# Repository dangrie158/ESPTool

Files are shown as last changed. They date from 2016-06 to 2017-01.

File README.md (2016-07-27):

# ESPTool
## A WiFi Security Swiss Army Knife

The ESPTool is a convenient Tool to test your WiFi Security against attackers.
It can demonstrate how easy it is to crack a WiFi Password or jam your WiFi so you cant access the internet.
This Tool is designed for education and self tests.

**Be aware that it is illegal to use this device on Networks other than your own.**

_**Disclaimer** The authors of this reposity are not accountable for any action users may perform with this tool_

## Hardware

The Hardware is designed to be a relative generic and reusable Module around the ESP8266 WiFi Plattform. The Schematic is loosley based on the [NodeMCU](http://nodemcu.com) Project, however instead of breaking out all the free pins, all pins are used for a bunch of devices.

The Device has the following Hardware

* SSD1306 based OLED Display, connected via I2C
* microSD Card Socket connected over the SPI interface
* 3 general purpose buttons
* ESP8266-12E Module
* TPS63031 Buck-/Boost-Converter with an input range from 1.8V - 5.5V
* MCP73831 Single-Cell LiPo Charger Chip
* CP2012 USB to UART converter Chip

## Software
The software is of course the part where all the security features are implemented.

It still is under heavy development. A List of planned features are listed here:

* Layer 1:
	* *Since the ESPs Radio is not really configurable it is not possible to create a WiFi Jammer that works by emitting broadband noise or any other Layer 1 attacks*
* Layer 2:
	* [Deauthentification attack](https://en.wikipedia.org/wiki/Wi-Fi_deauthentication_attack)
	* collecting authentification frames and save the keys to SD card for later decryption (using a wordlist on a computer, the ESP neither has enough memory nor enough processing power to crack them on the system)
	* arp spoofing and session hijacking when connected (needs investigation)
* Layer 3 (after connecting to an AP):
	* Host discovery (IP Scanner)
	* Ping flooding (ICMP Pings)
* Layer 4 (after connecting to an AP):
	* Port Scan on Host

### Incognito Features (TBD):
* Random MAC-Address on Power Up
* Random Mac Address while performing critical Tasks

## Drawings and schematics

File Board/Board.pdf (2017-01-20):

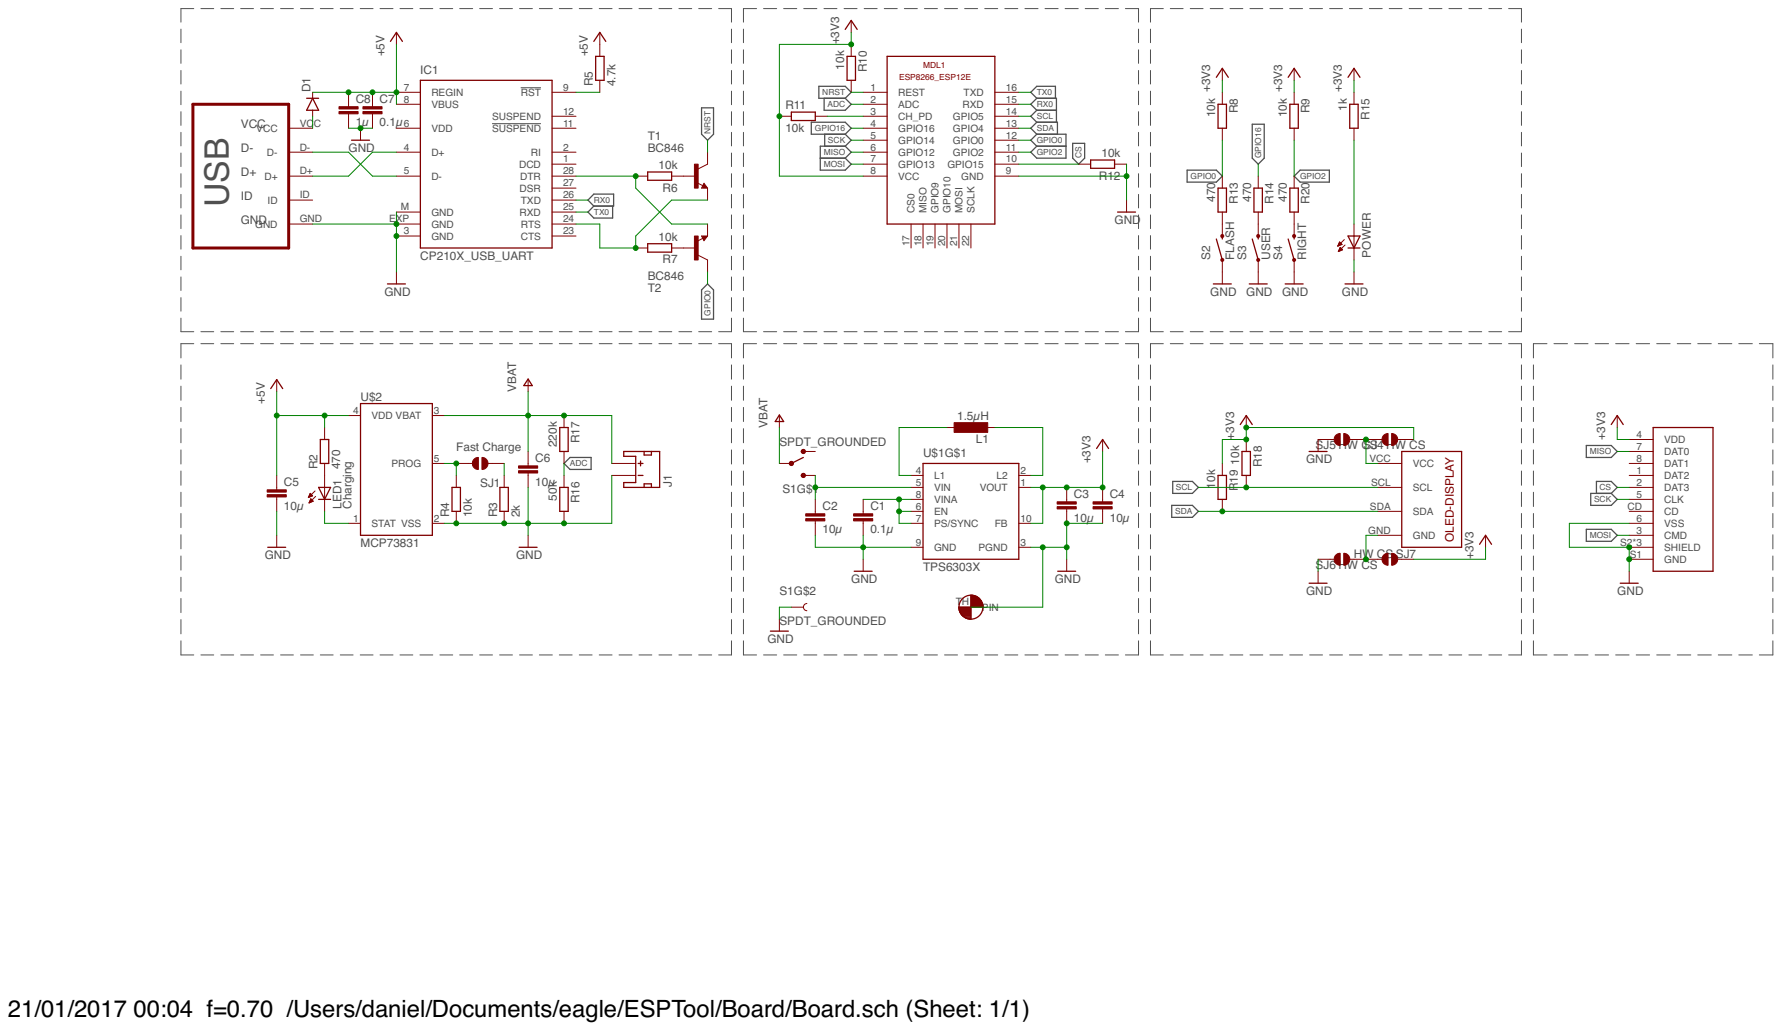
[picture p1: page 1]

HW CS HW CS GND

21/01/2017 00:04 f=0.70 /Users/daniel/Documents/eagle/ESPTool/Board/Board.sch (Sheet: 1/1)

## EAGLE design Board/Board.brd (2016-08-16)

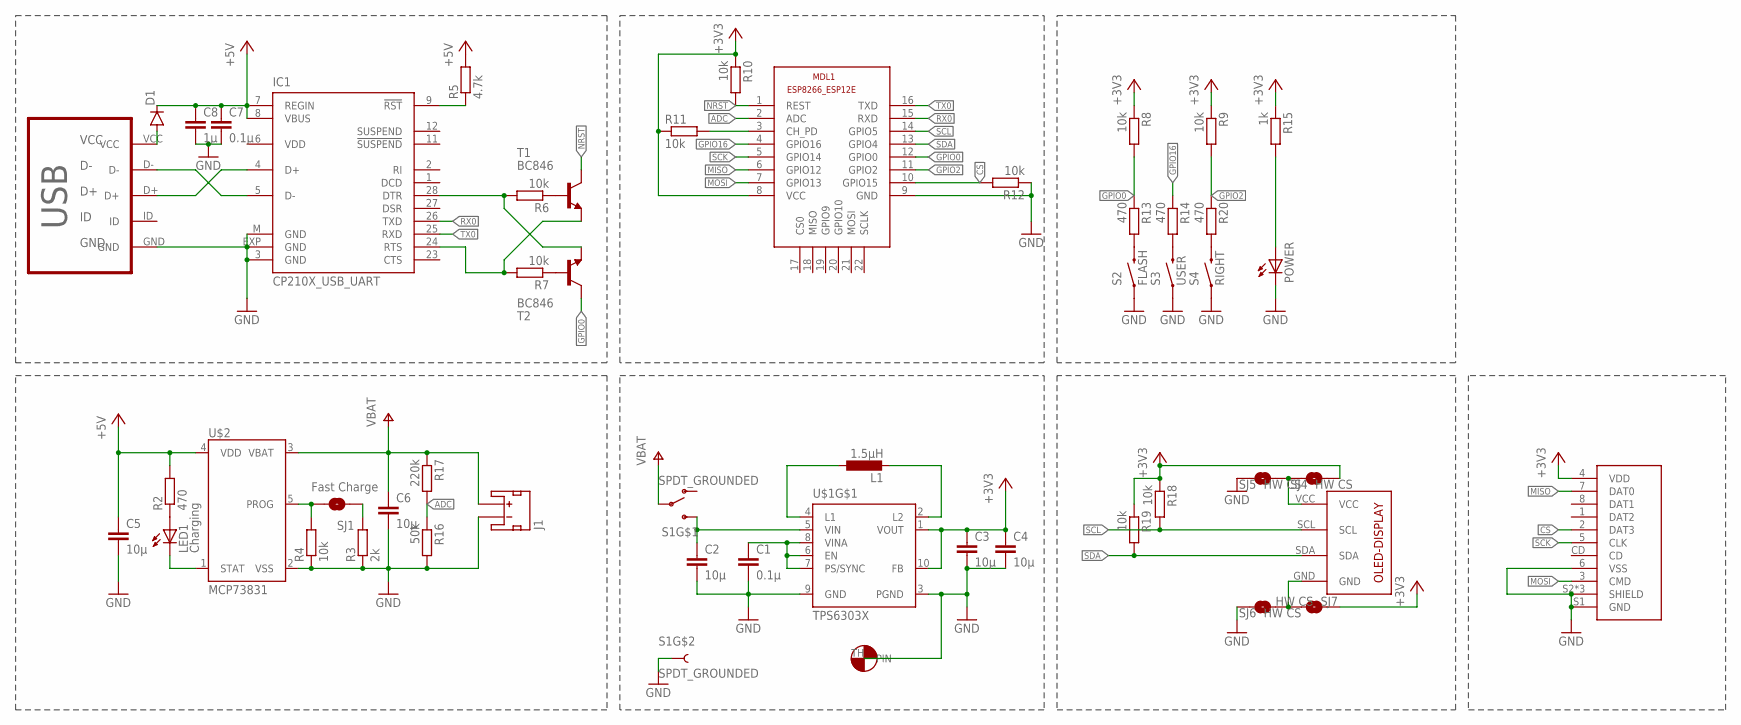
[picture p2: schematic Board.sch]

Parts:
C1, C7: 0.1µ; C0603
C2, C3, C4, C5, C6: 10µ; C0603
C8: 1µ; C0603
D1: DIODEBAS16; SOD-323
IC1: CP210X_USB_UART; MLP28
J1: JST_2MM_MALE; JST-2-SMD
L1: 1.5µH; L3225P
LED1: Charging; SML0805
MDL1: ESP8266-12EESP8266-ESP12E; ESP8266-ESP12E
POWER: LEDSML0805; SML0805
R2, R13, R14, R20: 470; R0603
R3: 2k; R0603
R4, R6, R7, R8, R9, R10, R11, R12, R18, R19: 10k; R0603
R5: 4.7k; R0603
R15: 1k; R0603
R16: 50k; R0603
R17: 220k; R0603
S1: SPDT_GROUNDED; SWITCH-SPST-SMD-A
S2: FLASH; TACTILE-SWITCH-1101NE
S3: USER; TACTILE-SWITCH-1101NE
S4: RIGHT; TACTILE-SWITCH-1101NE
SJ1: Fast Charge; SJ_2S-NO
SJ4, SJ5, SJ6, SJ7: HW CS; SJ_2S-NO
T1, T2: BC846; SOT23
U$1: TPS6303X; DSK10
U$2: MCP73831; SOT23-5
U$3: MICRO-USB-B; MICRO_USB_4_LEGS
U$4: MICRO_SD_SOCKET; MICRO_SD
U$6: OLED-I2C

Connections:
+3V3: C3.1, C4.1, MDL1.8 (VCC), R8.1, R9.1, R10.1, R11.1, R15.1, R18.1, R19.1, SJ4.1, SJ7.2, U$1.1 (VOUT), U$1.10 (FB), U$4.4 (VDD)
+5V: C5.1, C7.1, C8.1, D1.C, IC1.7 (REGIN), IC1.8 (VBUS), R2.2, R5.2, U$2.4 (VDD)
ADC: MDL1.2 (ADC), R16.1, R17.2
CS: MDL1.10 (GPIO15), R12.2, U$4.2 (DAT3)
GND: C1.2, C2.2, C3.2, C4.2, C5.2, C6.2, C7.2, C8.2, IC1.3 (GND), IC1.EXP (GND), IC1.M (GND), J1.1 (-), MDL1.9 (GND), POWER.C, R3.1, R4.1, R12.1, R16.2, S1.GND1 (1), S1.GND2 (1), S1.GND3 (1), S1.GND4 (1), S2.1, S3.1, S4.1, SJ5.2, SJ6.2, U$1.3 (PGND), U$1.9 (GND), U$1.TH (PIN), U$2.2 (VSS), U$3.GND, U$4.6 (VSS), U$4.S1 (GND), U$4.S2 (SHIELD), U$4.S3 (SHIELD), U$4.S4 (SHIELD)
GPIO0: MDL1.12 (GPIO0), R8.2, R13.1, T2.3 (C)
GPIO2: MDL1.11 (GPIO2), R9.2, R20.1
GPIO16: MDL1.4 (GPIO16), R14.1
MISO: MDL1.6 (GPIO12), U$4.7 (DAT0)
MOSI: MDL1.7 (GPIO13), U$4.3 (CMD)
unnamed: L1.1, U$1.4 (L1)
unnamed: L1.2, U$1.2 (L2)
unnamed: IC1.9 (!RST), R5.1
unnamed: D1.A, U$3.VCC
unnamed: IC1.5 (D-), U$3.D-
unnamed: C1.1, U$1.6 (EN), U$1.7 (PS/SYNC), U$1.8 (VINA)
unnamed: LED1.A, R2.1
unnamed: R4.2, SJ1.1, U$2.5 (PROG)
unnamed: LED1.C, U$2.1 (STAT)
unnamed: R3.2, SJ1.2
unnamed: MDL1.3 (CH_PD), R11.2
unnamed: IC1.4 (D+), U$3.D+
unnamed: IC1.28 (DTR), R6.2, T2.2 (E)
unnamed: R7.1, T2.1 (B)
unnamed: C2.1, S1.3 (S), U$1.5 (VIN)
unnamed: R6.1, T1.1 (B)
unnamed: IC1.24 (RTS), R7.2, T1.2 (E)
unnamed: R14.2, S3.2
unnamed: R13.2, S2.2
unnamed: POWER.A, R15.2
unnamed: SJ4.2, SJ5.1, U$6.VCC
unnamed: SJ6.1, SJ7.1, U$6.GND
unnamed: R20.2, S4.2
NRST: MDL1.1 (REST), R10.2, T1.3 (C)
RX0: IC1.26 (TXD), MDL1.15 (RXD)
SCK: MDL1.5 (GPIO14), U$4.5 (CLK)
SCL: MDL1.14 (GPIO5), R18.2, U$6.SCL
SDA: MDL1.13 (GPIO4), R19.2, U$6.SDA
TX0: IC1.25 (RXD), MDL1.16 (TXD)
V+: C6.1, J1.2 (+), R17.1, S1.2, U$2.3 (VBAT)
VDD: IC1.6 (VDD)

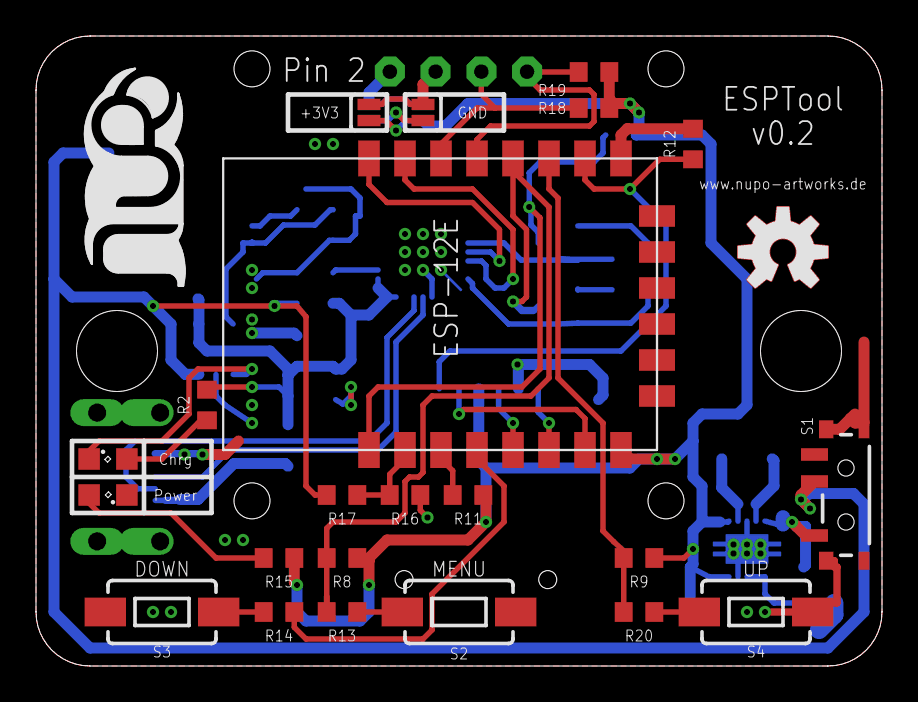
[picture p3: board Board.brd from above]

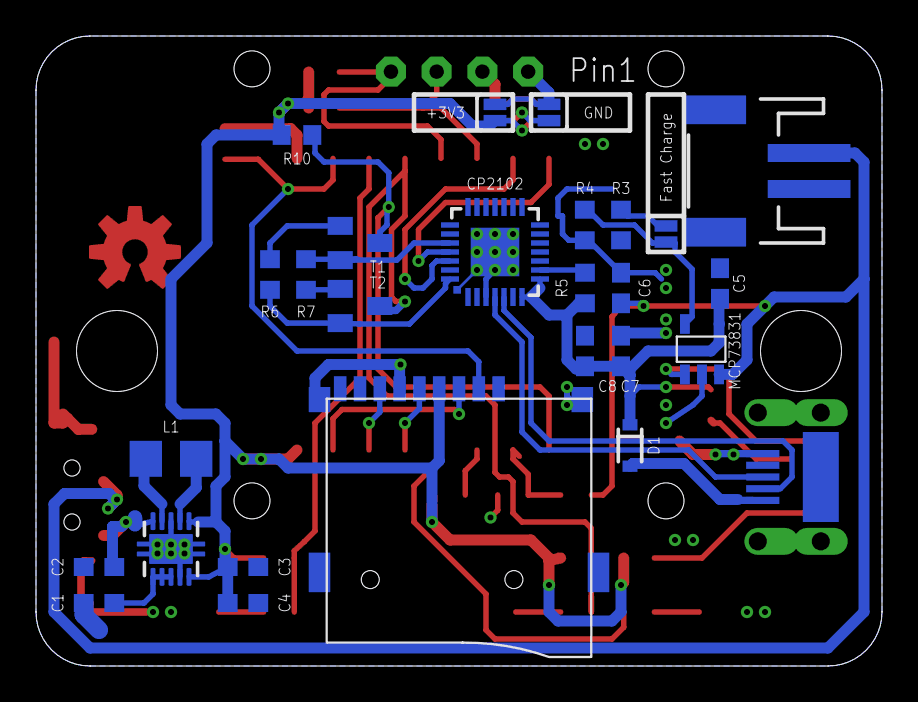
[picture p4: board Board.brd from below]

Board: 2 copper layers, 47.0 x 35.0 mm, 53 parts (27 on the bottom side), 40 nets.

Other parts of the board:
U$5: LOGO-SILKSCREEN
U$7: OSHW-LOGO-M
U$8: OSHW-LOGO-M_COPPER

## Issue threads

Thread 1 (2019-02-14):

Can it test one single password via wpa handshake ?

minanagehsalalma, 2019-02-14:

minanagehsalalma, 2020-01-30:
Yup it can

minanagehsalalma, 2020-01-31:
@dangrie158
Haha I found a tool that does so...
Any way about
"collecting authentification frames"
Can we get it to collect just the minimum packets possible for cracking ?

Closed 2020-01-31.

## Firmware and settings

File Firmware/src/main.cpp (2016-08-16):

#include <Arduino.h>
#include <Ticker.h>
#include <Wire.h>

#include "AnalogInput.h"
#include "Button.h"
#include "ConnectProcess.h"
#include "ESP8266WiFi.h"
#include "OccupationProcess.h"
#include "SSD1306.h"
#include "ScanHostsProcess.h"
#include "ScanProcess.h"

// Include custom images
#include "images.h"

#include "Pinger.h"
// include pin definitions
#include "defs.h"

SSD1306 display(0x3C, 4, 5);
AnalogInput batteryVoltage(VBAT_PIN, VBAT_MAX / ADC_MAX, 10);
Button down(12, true, true);
Button up(13, true, true);
Button left(14, true, true, true);
Ticker buttonUpdater;

ScanProcess scanner(&display);
Process *currentProcess = &scanner;

void updateButton() {
  down.update();
  up.update();
  left.update();
}

void drawStatusBar() {
  // draw the battery indicator and voltage
  float currentVoltage = batteryVoltage.readConverted();
  int screenWidthLeft = DISPLAY_WIDTH;

  const char *currentVoltageImage = NULL;
  if (currentVoltage >= 3.6) {
    currentVoltageImage = icon_battery_33;
  } else if (currentVoltage >= 3.4) {
    currentVoltageImage = icon_battery_23;
  } else if (currentVoltage >= 3.2) {
    currentVoltageImage = icon_battery_13;
  } else {
    currentVoltageImage = icon_battery_03;
  }

  display.drawXbm(DISPLAY_WIDTH - ICON_BATTERY_WIDTH, 2, ICON_BATTERY_WIDTH,
                  ICON_BATTERY_HEIGHT, currentVoltageImage);

  screenWidthLeft -= ICON_BATTERY_WIDTH + 2;

  display.setTextAlignment(TEXT_ALIGN_RIGHT);
  display.setFont(ArialMT_Plain_10);
  String voltageText = String(currentVoltage, 2) + "V";
  display.drawString(screenWidthLeft, 0, voltageText);
  display.drawLine(0, 11, DISPLAY_WIDTH, 11);

  screenWidthLeft -= display.getStringWidth(voltageText) + 4;

  // draw the sdcard icon if a card is present
  display.drawXbm(screenWidthLeft - ICON_SDCARD_WIDTH, 2, ICON_SDCARD_WIDTH,
                  ICON_SDCARD_HEIGHT, icon_sdcard);

  screenWidthLeft -= ICON_SDCARD_WIDTH + 4;

  // draw the wifi icon if connected
  if (WiFi.status() == WL_CONNECTED) {
    display.drawXbm(screenWidthLeft - ICON_WIFI_WIDTH, 2, ICON_WIFI_WIDTH,
                    ICON_WIFI_HEIGHT, icon_wifi);

    screenWidthLeft -= ICON_WIFI_WIDTH + 4;
  }

  // draw the current menu location
  String currentScreenName = currentProcess->getName();
  while (display.getStringWidth(currentScreenName) > screenWidthLeft) {
    currentScreenName.remove(currentScreenName.length() - 4);
    currentScreenName += "...";
  }

  display.setTextAlignment(TEXT_ALIGN_LEFT);
  display.drawString(0, 0, currentScreenName);
}

void setup() {
  display.init();

  display.flipScreenVertically();

  pinMode(VBAT_PIN, INPUT);

  Serial.begin(115200);
  Serial.println("lalalalala test");

  buttonUpdater.attach_ms(10, updateButton);

  currentProcess->initialize();

  scanner.setCallback([currentProcess](int selectedLan) {
    currentProcess = new ConnectProcess(&display, selectedLan);
    currentProcess->setCallback([currentProcess](int status) {
      if (status == 0) {
        currentProcess = new ScanHostsProcess(&display);
        currentProcess->initialize();
      } else {
        currentProcess = &scanner;
      }
    });
  });
}

void handleInput() {
  status_t status = up.getStatus();
  currentProcess->handleInput(Up, status);

  status = down.getStatus();
  currentProcess->handleInput(Down, status);

  status = left.getStatus();
  currentProcess->handleInput(Left, status);
}

void loop() {
  display.clear();
  drawStatusBar();

  currentProcess->update();

  handleInput();

  display.display();
}

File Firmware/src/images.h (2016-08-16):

#define ICON_BATTERY_WIDTH 16
#define ICON_BATTERY_HEIGHT 8

const char icon_battery_33[] PROGMEM = {0xfe, 0xff, 0x02, 0x80, 0xbb, 0xbb,
                                        0xb9, 0xbb, 0xb9, 0xbb, 0xbb, 0xbb,
                                        0x02, 0x80, 0xfe, 0xff};
const char icon_battery_23[] PROGMEM = {0xfe, 0xff, 0x02, 0x80, 0x83, 0xbb,
                                        0x81, 0xbb, 0x81, 0xbb, 0x83, 0xbb,
                                        0x02, 0x80, 0xfe, 0xff};
const char icon_battery_13[] PROGMEM = {0xfe, 0xff, 0x02, 0x80, 0x03, 0xb8,
                                        0x01, 0xb8, 0x01, 0xb8, 0x03, 0xb8,
                                        0x02, 0x80, 0xfe, 0xff};
const char icon_battery_03[] PROGMEM = {0xfe, 0xff, 0x02, 0x80, 0x03, 0x80,
                                        0x01, 0x80, 0x01, 0x80, 0x03, 0x80,
                                        0x02, 0x80, 0xfe, 0xff};

#define ICON_SDCARD_WIDTH 8
#define ICON_SDCARD_HEIGHT 8
const char icon_sdcard[] PROGMEM = {0x7f, 0x55, 0x55, 0x81,
                                    0x81, 0x81, 0x81, 0xff};

#define ICON_WIFI_WIDTH 8
#define ICON_WIFI_HEIGHT 8
const char icon_wifi[] PROGMEM = {0x3c, 0x42, 0x81, 0x3c,
                                  0x42, 0x00, 0x18, 0x00};

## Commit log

2016-06-29 placed silkscreen
    [Board.brd]
2016-06-29 added lables for navigation buttons
    [Board.brd]
2016-06-29 added lables to user and flash button
    [Board.brd]
2016-06-29 removed soldermask from vias
    [Board.brd]
2016-07-25 cleanup schematic
    [Board.brd, Board.sch]
2016-07-25 moved pins to new spi out and removed unused components
    [Board.brd, Board.sch]
2016-07-27 restructured repo to add firmware
    [Board.brd, Board.sch, Board30x60.brd]
2016-07-29 added reference designators to CS Line
    [Board.sch]
2016-07-29 Added Released Event after Button was held
2016-08-01 added opt-in double click functionality to buttons
2016-08-01 added switch to disable list items to be selectable in ListScreen
    this is handy if you want to display simple lists that are not selectable but scrollable (e.g. results or a summary)
2016-08-05 added MessageScreen to show simple messages with one action button
2016-08-16 added missing connection in rev2 on TX net
    [Board.brd]
2016-08-16 added missing wifi icon
    [images.h]
2017-01-20 added pdf schematic

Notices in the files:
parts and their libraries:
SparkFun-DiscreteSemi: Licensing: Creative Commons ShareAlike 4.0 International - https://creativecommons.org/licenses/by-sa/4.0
